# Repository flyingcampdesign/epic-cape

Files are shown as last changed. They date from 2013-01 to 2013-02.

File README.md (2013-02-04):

*STATUS:* The initial prototype PCB for this cape has been manufactured and is in the bring up phase.  A couple issues have been found that will require a new pcb spin.  Please do not fork this project until these issues have been fixed!  Check out <http://twitter.com/FlyingCamp> for updates on bring-up and test.

The Epic Cape is a cape for the BeagleBone that adds an 802.15.4 wireless mesh networking interface.  

The Epic Cape uses the open source Epic module (http://www.cs.berkeley.edu/~prabal/projects/epic/) which allows the cape to act as a compact egress router for low power sensor networks.  The Epic module is fully supported by the open source TinyOS (http://www.tinyos.net) sensor network operating system and features a complete 6lowpan/RPL IPv6 stack (http://docs.tinyos.net/tinywiki/index.php/BLIP_2.0) that allows transmission of IPv6 Packets over IEEE 802.15.4 networks.  The Epic Cape will allow you to develop an 802.15.4 wireless sensor network with IPv6 connectivity to each low power mesh endpoint.

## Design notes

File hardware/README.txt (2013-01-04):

Eagle Zip Release
=============

* Save board and schematic
* Create schematic PDF (<proj name>.pdf)
* Create BOM file (<proj name>.xlsx)
    * In schematic editor, execute "run bom.ulp"
    * Change "List Type" to "Values"
    * Change "Output Format" to "CSV"
    * "Save" as <proj name>.csv
    * Use Excel to convert to <proj name>.xlsx
* Execute "make eagle"

Fab Zip Release
===============

* Complete "Eagle Zip Release" steps
* Run CAM processor to generate Gerber files
* Create XYRS pick-n-place files
    * In layout editor, execute "run mountsmd.ulp"
    * Save as <proj name>.mnt and <proj name>.mnb
* Create photoplots PDF (<proj name>_photoplots.pdf)
* Execute "make fab"

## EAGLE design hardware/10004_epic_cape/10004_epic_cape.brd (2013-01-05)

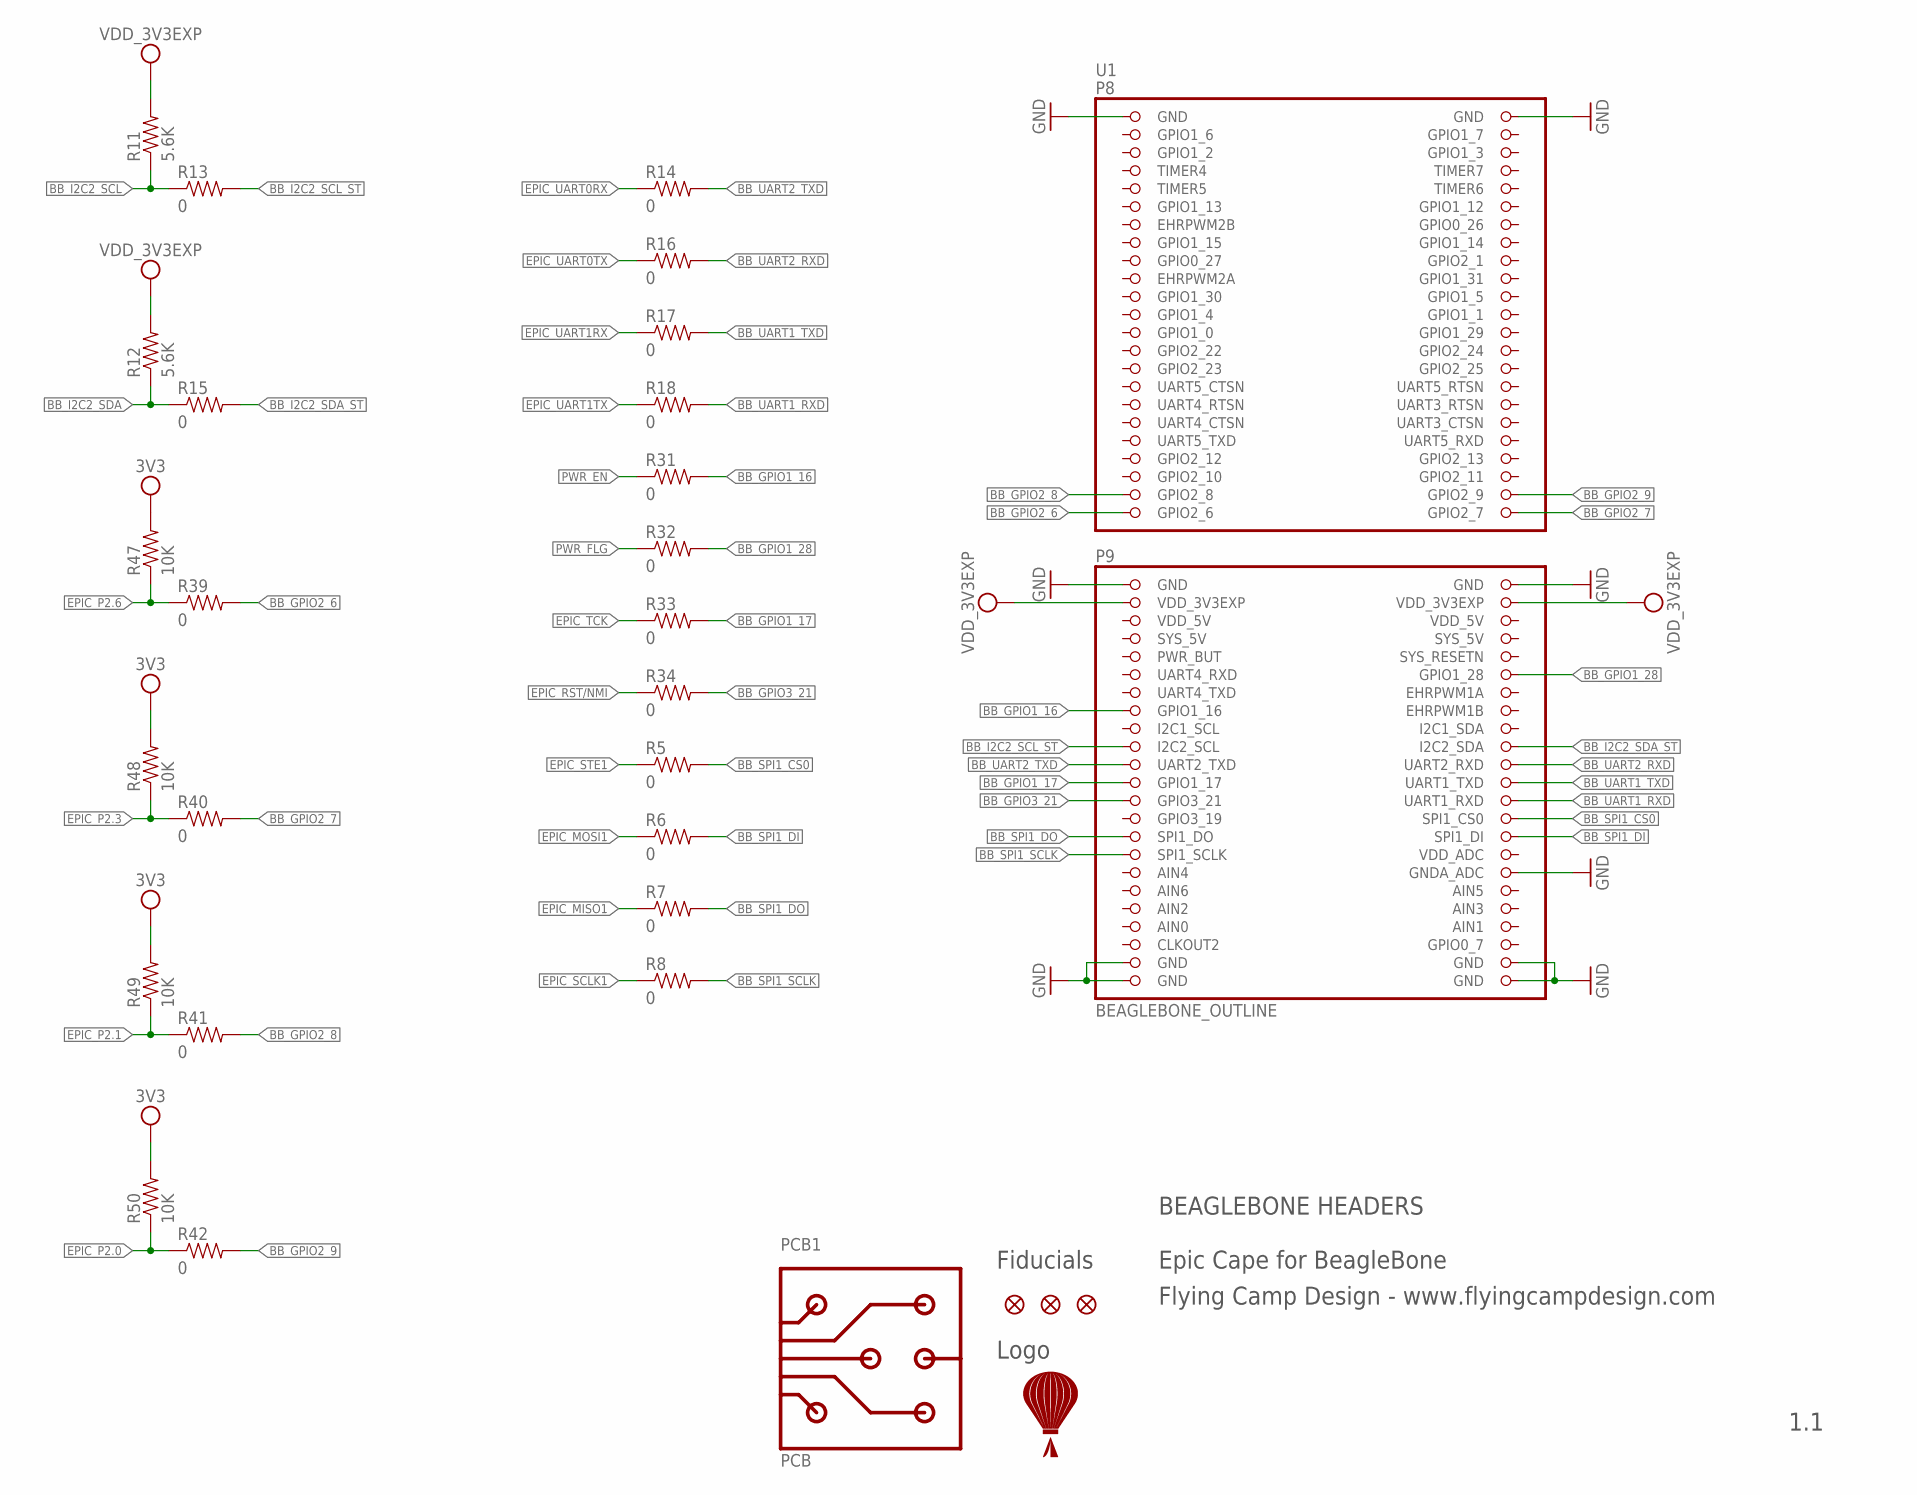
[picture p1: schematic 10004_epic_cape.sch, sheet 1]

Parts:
R5, R6, R7, R8, R13, R14, R15, R16, R17, R18, R31, R32, R33, R34, R39, R40, R41, R42: 0; RESC1005; MPN ERJ-2GE0R00X
R11, R12: 5.6K; RESC1005; MPN ERJ-2RKF5601X
R47, R48, R49, R50: 10K; RESC1005; MPN ERJ-2RKF1002X
U1: BEAGLEBONE_OUTLINE; BEAGLEBONE_SHIELD
U$2: LOGO
U$3, U$4, U$5: FIDUCIAL1X2.5; FIDUCIAL-1X2.5

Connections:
3V3: R47.2, R48.2, R49.2, R50.2; also elsewhere on the board
AIN0: U1.85 (AIN0)
AIN3: U1.84 (AIN3)
BB_GPIO1_16: R31.2, U1.61 (GPIO1_16)
BB_GPIO1_17: R33.2, U1.69 (GPIO1_17)
BB_GPIO1_28: R32.2, U1.58 (GPIO1_28)
BB_GPIO2_6: R39.2, U1.45 (GPIO2_6)
BB_GPIO2_7: R40.2, U1.46 (GPIO2_7)
BB_GPIO2_8: R41.2, U1.43 (GPIO2_8)
BB_GPIO2_9: R42.2, U1.44 (GPIO2_9)
BB_GPIO3_21: R34.2, U1.71 (GPIO3_21)
BB_I2C2_SCL: R11.1, R13.1; also elsewhere on the board
BB_I2C2_SCL_ST: R13.2, U1.65 (I2C2_SCL)
BB_I2C2_SDA: R12.1, R15.1; also elsewhere on the board
BB_I2C2_SDA_ST: R15.2, U1.66 (I2C2_SDA)
BB_SPI1_CS0: R5.2, U1.74 (SPI1_CS0)
BB_SPI1_DI: R6.2, U1.76 (SPI1_DI)
BB_SPI1_DO: R7.2, U1.75 (SPI1_DO)
BB_SPI1_SCLK: R8.2, U1.77 (SPI1_SCLK)
BB_UART1_RXD: R18.2, U1.72 (UART1_RXD)
BB_UART1_TXD: R17.2, U1.70 (UART1_TXD)
BB_UART2_RXD: R16.2, U1.68 (UART2_RXD)
BB_UART2_TXD: R14.2, U1.67 (UART2_TXD)
EPIC_MISO1: R7.1; also elsewhere on the board
EPIC_MOSI1: R6.1; also elsewhere on the board
EPIC_P2.0: R42.1, R50.1; also elsewhere on the board
EPIC_P2.1: R41.1, R49.1; also elsewhere on the board
EPIC_P2.3: R40.1, R48.1; also elsewhere on the board
EPIC_P2.6: R39.1, R47.1; also elsewhere on the board
EPIC_RST/NMI: R34.1; also elsewhere on the board
EPIC_SCLK1: R8.1; also elsewhere on the board
EPIC_STE1: R5.1; also elsewhere on the board
EPIC_TCK: R33.1; also elsewhere on the board
EPIC_UART0RX: R14.1; also elsewhere on the board
EPIC_UART0TX: R16.1; also elsewhere on the board
EPIC_UART1RX: R17.1; also elsewhere on the board
EPIC_UART1TX: R18.1; also elsewhere on the board
GND: U1.1 (GND), U1.2 (GND), U1.47 (GND), U1.48 (GND), U1.80 (GNDA_ADC), U1.89 (GND), U1.90 (GND), U1.91 (GND), U1.92 (GND); also elsewhere on the board
GPIO1_6: U1.3 (GPIO1_6)
GPIO1_7: U1.4 (GPIO1_7)
GPIO2_11: U1.42 (GPIO2_11)
PWR_EN: R31.1; also elsewhere on the board
PWR_FLG: R32.1; also elsewhere on the board
VDD_3V3EXP: R11.2, R12.2, U1.49 (VDD_3V3EXP), U1.50 (VDD_3V3EXP); also elsewhere on the board
VDD_5V: U1.51 (VDD_5V), U1.52 (VDD_5V)

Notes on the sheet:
Epic Cape for BeagleBone
Flying Camp Design - www.flyingcampdesign.com
1.1
Logo
Fiducials
BEAGLEBONE HEADERS

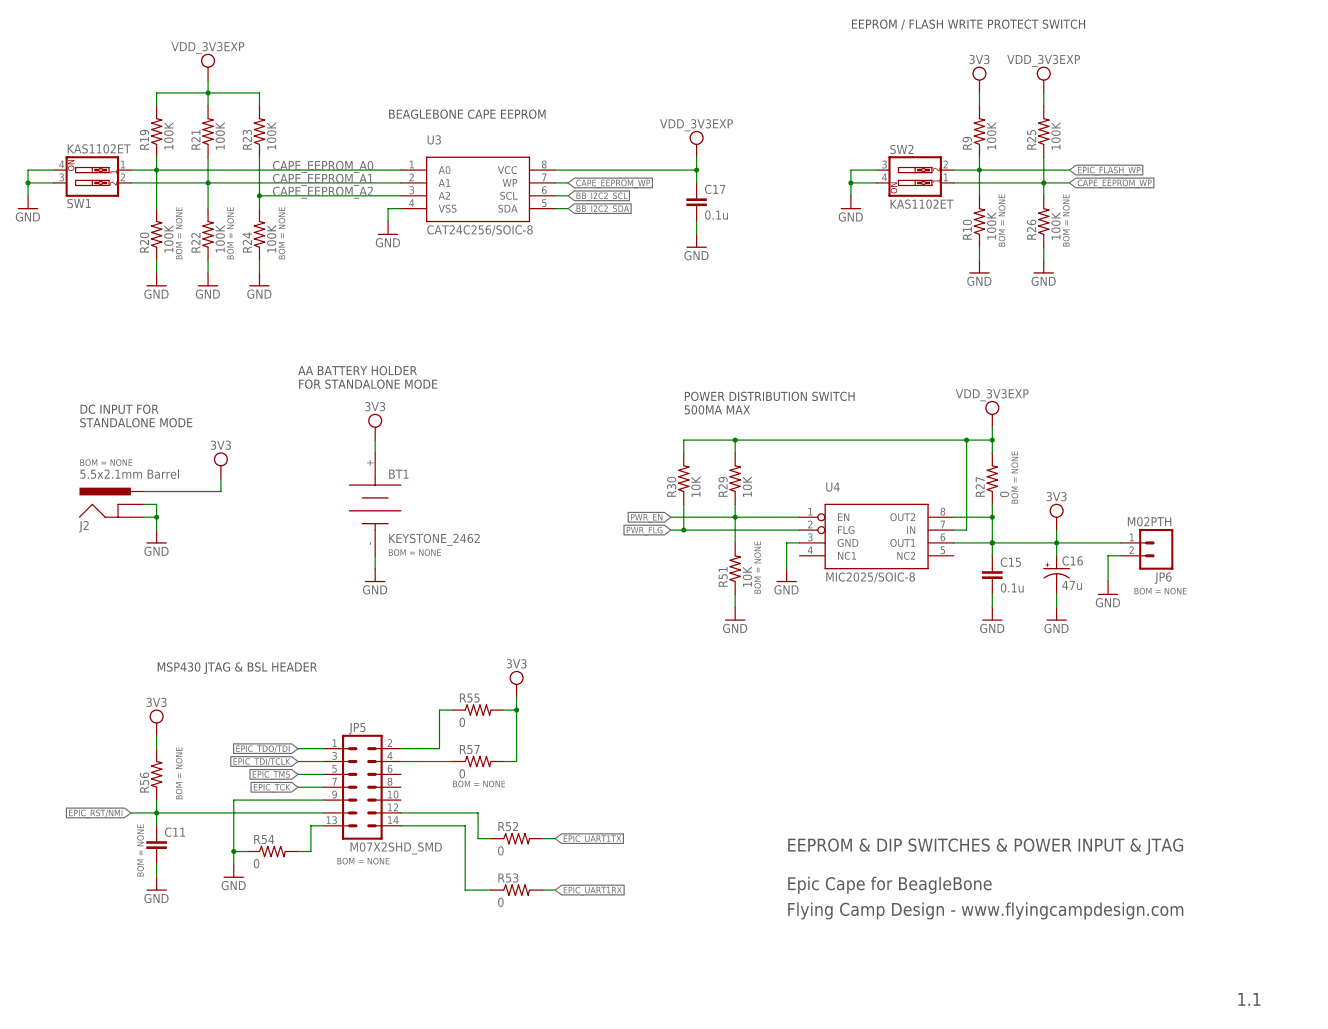
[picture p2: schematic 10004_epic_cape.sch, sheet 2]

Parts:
BT1: KEYSTONE_2462; MPN 2462
C11: CAPACITOR1005; CAPC1005
C15, C17: 0.1u; CAPC1005; MPN C0402C104K9RACTU
C16: 47u; EIA3216; MPN T491A476M006AT
J2: 5.5x2.1mm Barrel; POWER_JACK_SMD; MPN PJ-002AH-SMT-TR
JP5: M07X2SHD_SMD; 2X7-SHROUDED_SMD
JP6: M02PTH; 1X02
R9, R10, R19, R20, R21, R22, R23, R24, R25, R26: 100K; RESC1005; MPN ERJ-2RKF1003X
R27: 0; RESC3216; MPN ERJ-8GEY0R00V
R29, R30, R51: 10K; RESC1005; MPN ERJ-2RKF1002X
R52, R53, R54, R55, R57: 0; RESC1005; MPN ERJ-2GE0R00X
R56: RESISTOR1005; RESC1005
SW1, SW2: KAS1102ET; DIPSWITCH-02; MPN KAS1102ET
U3: CAT24C256/SOIC-8; SOIC-8; MPN CAT24C256WI-GT3
U4: MIC2025/SOIC-8; SOIC-8; MPN MIC2025-1YM

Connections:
3V3: BT1.+, C15.1, C16.A (+), J2.VIN0 (PWR), JP6.1, R9.2, R27.1, R55.2, R56.2, R57.2, U4.6 (OUT1), U4.8 (OUT2); also elsewhere on the board
BB_I2C2_SCL: U3.6 (SCL); also elsewhere on the board
BB_I2C2_SDA: U3.5 (SDA); also elsewhere on the board
CAPE_EEPROM_A0: R19.1, R20.2, SW1.1, U3.1 (A0)
CAPE_EEPROM_A1: R21.1, R22.2, SW1.2, U3.2 (A1)
CAPE_EEPROM_A2: R23.1, R24.2, U3.3 (A2)
CAPE_EEPROM_WP: R25.1, R26.2, SW2.1, U3.7 (WP)
EPIC_FLASH_WP: R9.1, R10.2, SW2.2; also elsewhere on the board
EPIC_RST/NMI: C11.1, JP5.11, R56.1; also elsewhere on the board
EPIC_TCK: JP5.7; also elsewhere on the board
EPIC_TDI/TCLK: JP5.3; also elsewhere on the board
EPIC_TDO/TDI: JP5.1; also elsewhere on the board
EPIC_TMS: JP5.5; also elsewhere on the board
EPIC_UART1RX: R53.2; also elsewhere on the board
EPIC_UART1TX: R52.2; also elsewhere on the board
GND: BT1.-, C11.2, C15.2, C16.C (-), C17.2, J2.GND (GNDBREAK), J2.P$4 (GND), JP5.9, JP6.2, R10.1, R20.1, R22.1, R24.1, R26.1, R51.1, R54.1, SW1.3, SW1.4, SW2.3, SW2.4, U3.4 (VSS), U4.3 (GND); also elsewhere on the board
unnamed: JP5.13, R54.2
unnamed: JP5.12, R52.1
unnamed: JP5.14, R53.1
PWR_EN: R29.1, R51.2, U4.1 (EN); also elsewhere on the board
PWR_FLG: R30.1, U4.2 (FLG); also elsewhere on the board
VCCTARGET: JP5.4, R57.1
VCCTOOL: JP5.2, R55.1
VDD_3V3EXP: C17.1, R19.2, R21.2, R23.2, R25.2, R27.2, R29.2, R30.2, U3.8 (VCC), U4.7 (IN); also elsewhere on the board

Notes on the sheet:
Epic Cape for BeagleBone
Flying Camp Design - www.flyingcampdesign.com
1.1
EEPROM & DIP SWITCHES & POWER INPUT & JTAG
DC INPUT FOR STANDALONE MODE
POWER DISTRIBUTION SWITCH 500MA MAX
EEPROM / FLASH WRITE PROTECT SWITCH
BEAGLEBONE CAPE EEPROM
MSP430 JTAG & BSL HEADER
AA BATTERY HOLDER FOR STANDALONE MODE

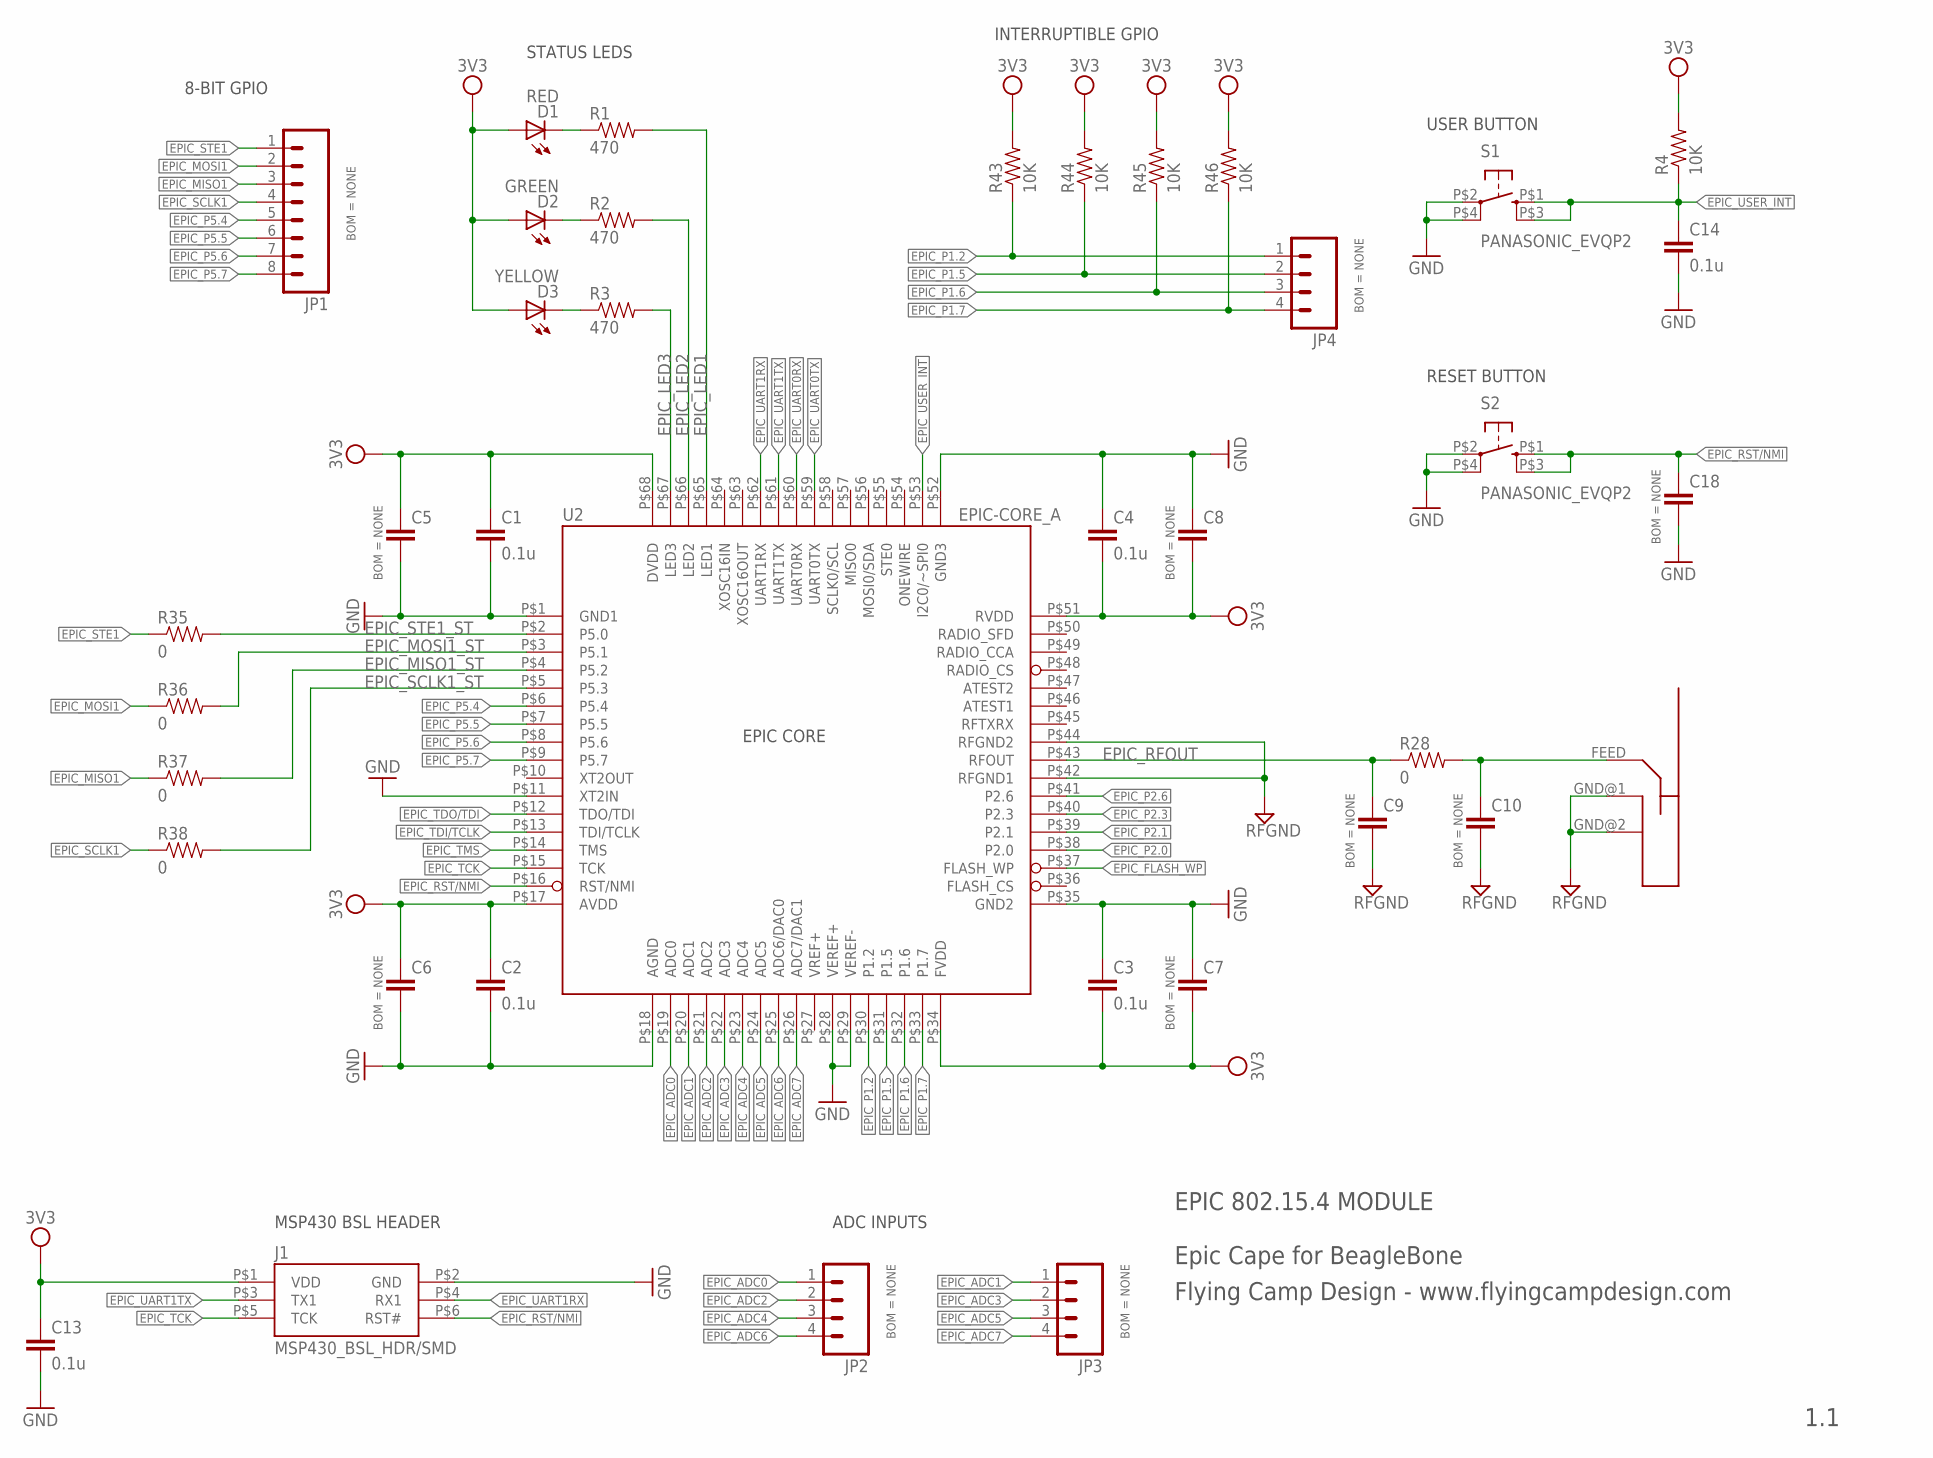
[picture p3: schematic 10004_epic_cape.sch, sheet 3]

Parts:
ANT1: 2.4GHZ_INVERTED_F_ANTENNA
C1, C2, C3, C4, C13, C14: 0.1u; CAPC1005; MPN C0402C104K9RACTU
C5, C6, C7, C8: CAPACITOR2012; CAPC2012
C9, C10, C18: CAPACITOR1005; CAPC1005
D1: RED; LEDC1608; MPN QTLP600C7TR
D2: GREEN; LEDC1608; MPN QTLP601C4TR
D3: YELLOW; LEDC1608; MPN QTLP600CYTR
J1: MSP430_BSL_HDR/SMD; HIROSE_DF11G-XXDP-2V; MPN DF11G-6DP-2V(50)
JP1: M081X08; 1X08
JP2, JP3, JP4: M04PTH; 1X04
R1, R2, R3: 470; RESC1005; MPN ERJ-2RKF4700X
R4, R43, R44, R45, R46: 10K; RESC1005; MPN ERJ-2RKF1002X
R28, R35, R36, R37, R38: 0; RESC1005; MPN ERJ-2GE0R00X
S1, S2: PANASONIC_EVQP2; MPN EVQ-P2K02Q
U2: EPIC-CORE_A; EPIC_LCC68; MPN EPIC-CORE-PCB

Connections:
3V3: C1.1, C2.1, C3.2, C4.2, C5.1, C6.1, C7.2, C8.2, C13.1, D1.A, D2.A, D3.A, J1.P$1 (VDD), R4.2, R43.2, R44.2, R45.2, R46.2, U2.P$17 (AVDD), U2.P$34 (FVDD), U2.P$51 (RVDD), U2.P$68 (DVDD); also elsewhere on the board
EPIC_ADC0: JP2.1, U2.P$19 (ADC0)
EPIC_ADC1: JP3.1, U2.P$20 (ADC1)
EPIC_ADC2: JP2.2, U2.P$21 (ADC2)
EPIC_ADC3: JP3.2, U2.P$22 (ADC3)
EPIC_ADC4: JP2.3, U2.P$23 (ADC4)
EPIC_ADC5: JP3.3, U2.P$24 (ADC5)
EPIC_ADC6: JP2.4, U2.P$25 (ADC6/DAC0)
EPIC_ADC7: JP3.4, U2.P$26 (ADC7/DAC1)
EPIC_FLASH_WP: U2.P$37 (FLASH_WP); also elsewhere on the board
EPIC_LED1: R1.2, U2.P$65 (LED1)
EPIC_LED2: R2.2, U2.P$66 (LED2)
EPIC_LED3: R3.2, U2.P$67 (LED3)
EPIC_MISO1: JP1.3, R37.1; also elsewhere on the board
EPIC_MISO1_ST: R37.2, U2.P$4 (P5.2)
EPIC_MOSI1: JP1.2, R36.1; also elsewhere on the board
EPIC_MOSI1_ST: R36.2, U2.P$3 (P5.1)
EPIC_P1.2: JP4.1, R43.1, U2.P$30 (P1.2)
EPIC_P1.5: JP4.2, R44.1, U2.P$31 (P1.5)
EPIC_P1.6: JP4.3, R45.1, U2.P$32 (P1.6)
EPIC_P1.7: JP4.4, R46.1, U2.P$33 (P1.7)
EPIC_P2.0: U2.P$38 (P2.0); also elsewhere on the board
EPIC_P2.1: U2.P$39 (P2.1); also elsewhere on the board
EPIC_P2.3: U2.P$40 (P2.3); also elsewhere on the board
EPIC_P2.6: U2.P$41 (P2.6); also elsewhere on the board
EPIC_P5.4: JP1.5, U2.P$6 (P5.4)
EPIC_P5.5: JP1.6, U2.P$7 (P5.5)
EPIC_P5.6: JP1.7, U2.P$8 (P5.6)
EPIC_P5.7: JP1.8, U2.P$9 (P5.7)
EPIC_RFOUT: C9.1, R28.1, U2.P$43 (RFOUT)
EPIC_RST/NMI: C18.1, J1.P$6 (RST#), S2.P$1 (1), S2.P$3 (3), U2.P$16 (RST/NMI); also elsewhere on the board
EPIC_SCLK1: JP1.4, R38.1; also elsewhere on the board
EPIC_SCLK1_ST: R38.2, U2.P$5 (P5.3)
EPIC_STE1: JP1.1, R35.1; also elsewhere on the board
EPIC_STE1_ST: R35.2, U2.P$2 (P5.0)
EPIC_TCK: J1.P$5 (TCK), U2.P$15 (TCK); also elsewhere on the board
EPIC_TDI/TCLK: U2.P$13 (TDI/TCLK); also elsewhere on the board
EPIC_TDO/TDI: U2.P$12 (TDO/TDI); also elsewhere on the board
EPIC_TMS: U2.P$14 (TMS); also elsewhere on the board
EPIC_UART0RX: U2.P$60 (UART0RX); also elsewhere on the board
EPIC_UART0TX: U2.P$59 (UART0TX); also elsewhere on the board
EPIC_UART1RX: J1.P$4 (RX1), U2.P$62 (UART1RX); also elsewhere on the board
EPIC_UART1TX: J1.P$3 (TX1), U2.P$61 (UART1TX); also elsewhere on the board
EPIC_USER_INT: C14.1, R4.1, S1.P$1 (1), S1.P$3 (3), U2.P$53 (I2C0/~SPI0)
FEED: ANT1.FEED, C10.1, R28.2
GND: C1.2, C2.2, C3.1, C4.1, C5.2, C6.2, C7.1, C8.1, C13.2, C14.2, C18.2, J1.P$2 (GND), S1.P$2 (2), S1.P$4 (4), S2.P$2 (2), S2.P$4 (4), U2.P$1 (GND1), U2.P$11 (XT2IN), U2.P$18 (AGND), U2.P$28 (VEREF+), U2.P$29 (VEREF-), U2.P$35 (GND2), U2.P$52 (GND3); also elsewhere on the board
unnamed: D1.C, R1.1
unnamed: D2.C, R2.1
unnamed: D3.C, R3.1
RFGND: ANT1.GND@1 (GND), ANT1.GND@2 (GND), C9.2, C10.2, U2.P$42 (RFGND1), U2.P$44 (RFGND2)

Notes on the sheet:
USER BUTTON
RESET BUTTON
STATUS LEDS
MSP430 BSL HEADER
Epic Cape for BeagleBone
Flying Camp Design - www.flyingcampdesign.com
1.1
EPIC CORE
EPIC 802.15.4 MODULE
INTERRUPTIBLE GPIO
ADC INPUTS
8-BIT GPIO

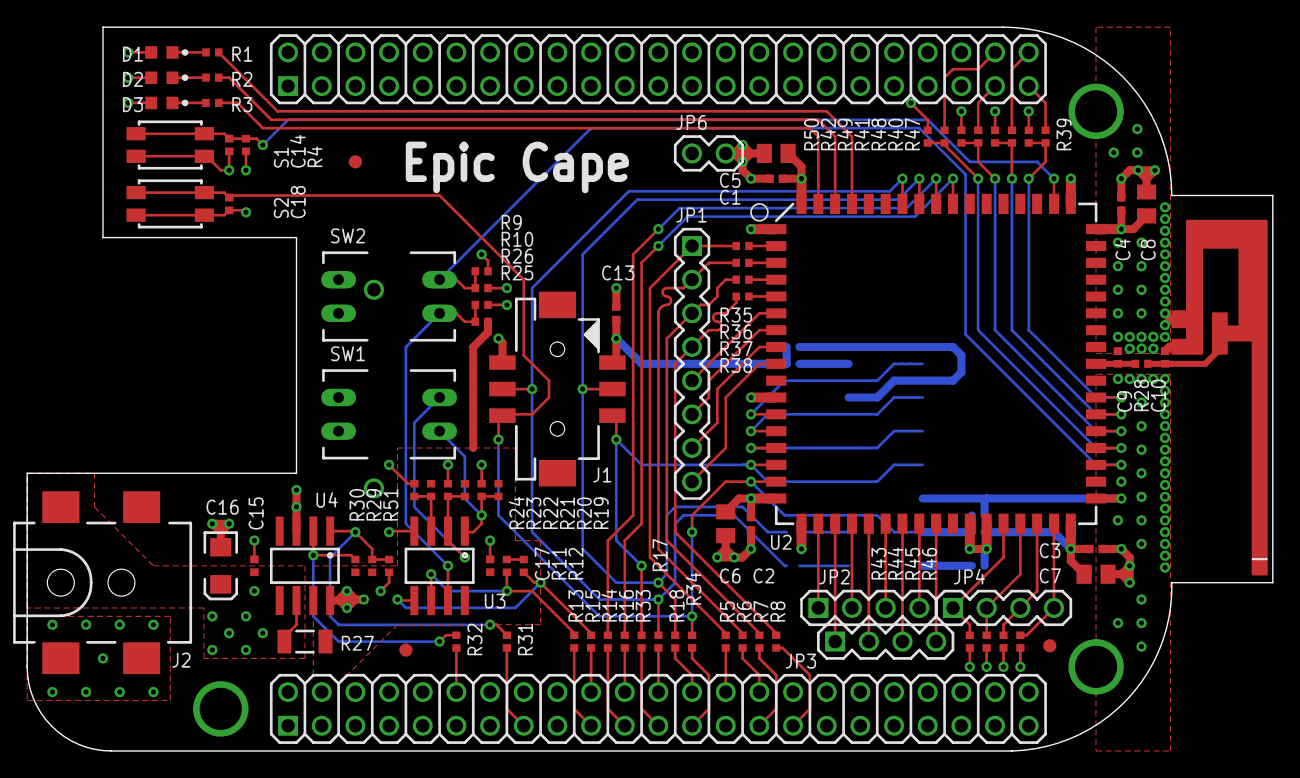
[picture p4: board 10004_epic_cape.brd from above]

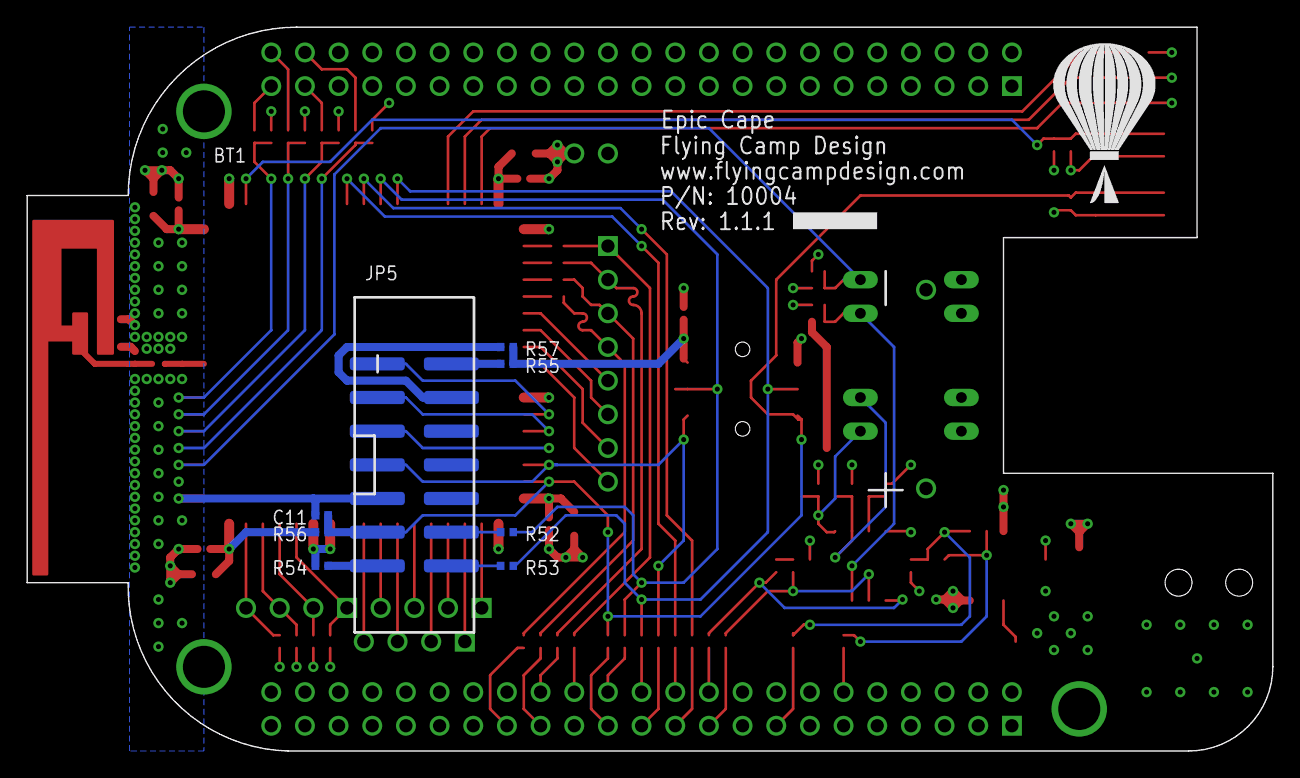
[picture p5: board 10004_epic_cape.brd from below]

Board: 4 copper layers, 94.0 x 54.6 mm, 99 parts (10 on the bottom side), 83 nets.

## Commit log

2013-01-01 Add Eagle schematic and board
    [10004_epic_cape.brd, 10004_epic_cape.sch, 10004_epic_cape.xls]
2013-01-04 Update design
    [10004_epic_cape.brd, 10004_epic_cape.csv, 10004_epic_cape.sch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]
2013-01-05 Release 1.1.1
    [10004_epic_cape.brd, 10004_epic_cape.csv, 10004_epic_cape.sch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]
2013-01-09 Update PCB readme to match 66each.com specs

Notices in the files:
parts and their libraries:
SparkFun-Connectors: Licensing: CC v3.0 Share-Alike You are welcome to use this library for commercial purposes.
